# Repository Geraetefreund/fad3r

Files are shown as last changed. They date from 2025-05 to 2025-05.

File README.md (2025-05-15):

# fad3r

v0.2 / 2025-05-14

Improved preset storage in EEPROM. Faders can now have indiviual MIDI channels.  

Load preset:  
``` F0 7D 40 <preset> F7```

Store current CC/Channel values to preset:  
```F0 7D 41 <preset> F7```

Set CCs and Channels for preset (remember dec to hex!):  
```F0 7D 42 <preset> <cc1> <cc2> <cc3> <ch1> <ch2> <ch3> F7```  

Dump preset: ``` F0 7D 43 <preset> F7```  

Returns: ```F0 7D 43 <preset> <cc1> <cc2> <cc3> <ch1> <ch2> <ch3> F7```

Get current preset: 
``` F0 7D 44 00 F7``` returns ```F0 7D 44 <current preset> F7```

=================
v0.1 / 2020-02-12

Firmware for Teensy LC (legacy) controlling three faders via USB Midi  

https://www.pjrc.com/store/teensylc.html  
https://www.pjrc.com/teensy/td_midi.html  

``` F0 7D <cc1> <cc2> <cc3> F7```
remember to convert from dec to hex!

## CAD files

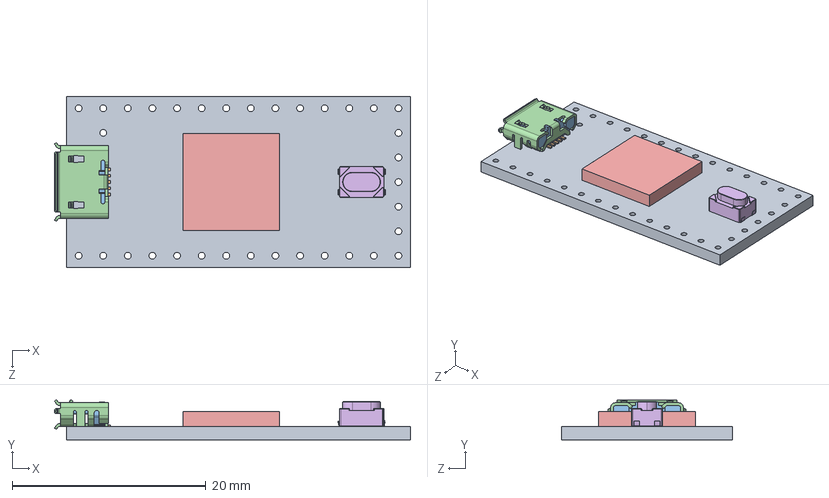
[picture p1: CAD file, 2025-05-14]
hardware/teensy.pretty-master/Teensy_4.0_Assembly.STEP
36.8 x 4.12 x 17.7 mm
Teensy_4.0_PCB
Micro USB-B Female 5Pin SMD
NXP iMXRT1062
SKRPACE010 v4

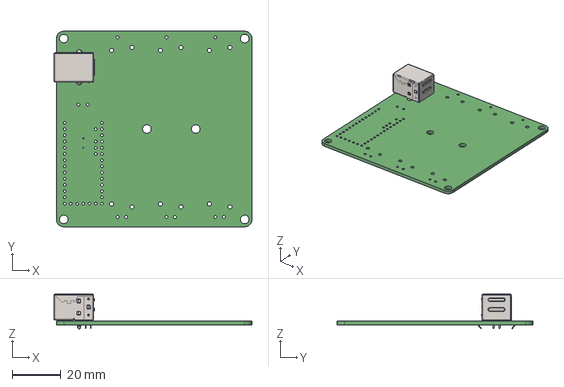
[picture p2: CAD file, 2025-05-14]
hardware/midi fader.step
81.0 x 80.0 x 14.2 mm

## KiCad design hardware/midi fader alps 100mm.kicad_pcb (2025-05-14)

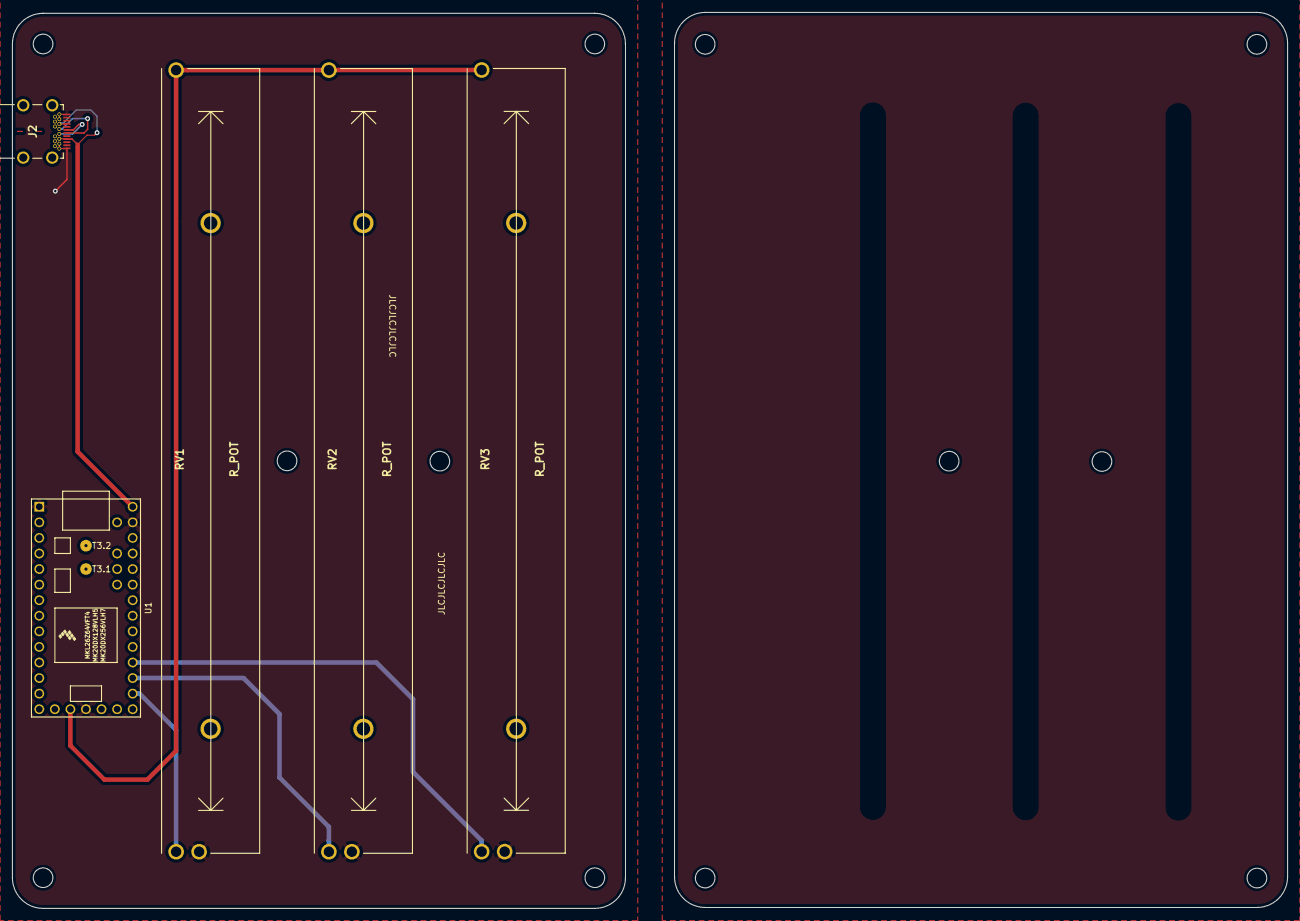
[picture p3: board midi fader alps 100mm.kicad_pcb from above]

Board: 2 copper layers, 100.0 x 146.0 mm, 5 parts (0 on the bottom side), 8 nets.

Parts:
J2: 632723300011
RV1, RV2, RV3: R_POT; Alps_RSA0N111900Q
U1: Teensy-LC; Teensy30_31_32_LC

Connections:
+3V3: RV1.3, RV2.3, RV3.3, U1.16
+5V: J2.A4, J2.A9, J2.B4, J2.B9, U1.33
/ADC_1: RV1.2, U1.21
/ADC_2: RV2.2, U1.22
/ADC_3: RV3.2, U1.23
/D+: J2.A6, J2.B6
/D-: J2.A7, J2.B7
GND: J2.1, J2.2, J2.A1, J2.A12, J2.B1, J2.B12, RV1.1, RV2.1, RV3.1, U1.1, U1.17, U1.32

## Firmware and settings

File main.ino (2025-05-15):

//Fad3r
//v0.2 / 2025-05-14

#include <EEPROM.h>

/* EEPROM layout - Teensy LC has 128 avaialble
Preset      Addr      Contents
0           0         CC1 CC2 CC3
            3         CH1 CH2 CH3
1           6         ...
...         ...       ...
Active      24        Current preset
*/
const int NUM_FADERS = 3;
const int NUM_PRESETS = 4;
const int BYTES_PER_PRESET = 6; // 3 CC + 3 CH
const int ACTIVE_PRESET_ADDR = NUM_PRESETS * BYTES_PER_PRESET; // stores location pointing to current preset

const int EEPROM_address[3] = {0, 1, 2};

// Fader analog input pins
const int pins[NUM_FADERS] = {A0, A1, A2}; // A0 = Fader 1, A1 = Fader 2, A2 = Fader 3

// MIDI CC and MIDI channel mappings
uint8_t cc[NUM_FADERS];
uint8_t channel[NUM_FADERS];

uint8_t currentPreset = 0;
bool sysexHandled = false;

// Previous analog values for change detection and smoothing
int oldValue[NUM_FADERS] = {0, 0, 0};

// Calling usbMIDI.getType() in every loop iteration is too laggy
// simple millis timer to the rescue.
unsigned long lastSysExCheck = 0;
const unsigned long sysexInterval = 20; // ms

void setup() {
  for (int i = 0; i < NUM_FADERS; i++) {
    pinMode(pins[i], INPUT);
  }

  currentPreset = EEPROM.read(ACTIVE_PRESET_ADDR);
  if (currentPreset >= NUM_PRESETS) currentPreset = 0;

  loadPreset(currentPreset);
}

void loop() {
  usbMIDI.read(); // Keep MIDI input buffer active

  // check for SysEx only every 20ms. Poor MIDI buffer gets too excited otherwise...
  if (millis() - lastSysExCheck >= sysexInterval) {
    handleSysEx();
  }

  // Fader reading and sending
  for (int i = 0; i < NUM_FADERS; i++) {
    int val = getFaderValue(i);
    if (val < 255) { // 255 means no significant change
      usbMIDI.sendControlChange(cc[i], val, channel[i]);
    }
  }
}

// Reads fader value and checks for significant change
int getFaderValue(int index) {
  int value = analogRead(pins[index]); // 0–1023
  if (abs(value - oldValue[index]) >= 8) { // Change threshold
    oldValue[index] = value;
    return (value < 8) ? 0 : (value >> 3); // Scale to 0–127
  }
  return 255; // No change
}

void loadPreset(uint8_t preset) {
  if (preset >= NUM_PRESETS) return;
  int base = preset * BYTES_PER_PRESET;
  for (int i = 0; i < NUM_FADERS; i++) {
    cc[i] = EEPROM.read(base + i);
    channel[i] = EEPROM.read(base + NUM_FADERS + i);
  }
}


void applyPreset(uint8_t preset) {
  loadPreset(preset);
  currentPreset = preset;
  EEPROM.update(ACTIVE_PRESET_ADDR, preset);
}

void savePreset(uint8_t preset) {
  if (preset >= NUM_PRESETS) return;
  int base = preset * BYTES_PER_PRESET;
  for (int i = 0; i < NUM_FADERS; i++) {
    EEPROM.update(base + i, cc[i]);
    EEPROM.update(base + NUM_FADERS + i, channel[i]);
  }
}

void dumpPreset(uint8_t preset) {
  if (preset >= NUM_PRESETS) return;
  uint8_t data[11]; // oops was 10 before.
  data[0] = 0xF0;
  data[1] = 0x7D;
  data[2] = 0x43; // Dump command
  data[3] = preset;
  int base = preset * BYTES_PER_PRESET;
  for (int i = 0; i < NUM_FADERS; i++) {
    data[4 + i] = EEPROM.read(base + i);  // CC
    data[4 + NUM_FADERS + i] = EEPROM.read(base + NUM_FADERS + i); // CH
  }
  data[10] = 0xF7;
  usbMIDI.sendSysEx(11, data, true);
}

void handleSysEx() {
  static uint8_t lastCommand = 0x00;
  static uint8_t lastPreset = 0xFF;

  if (usbMIDI.getType() == usbMIDI.SystemExclusive) {
    const uint8_t* data = usbMIDI.getSysExArray();
    unsigned int len = usbMIDI.getSysExArrayLength();

    if (len >= 5 && data[0] == 0xF0 && data[1] == 0x7D && data[len - 1] == 0xF7) {
      uint8_t command = data[2];
      uint8_t preset = data[3];

      // Avoid re-processing the same message repeatedly
      if (command == lastCommand && preset == lastPreset) return;

      lastCommand = command;
      lastPreset = preset;

      switch (command) {
        case 0x40: applyPreset(preset); break;
        case 0x41: savePreset(preset); break;
        case 0x42:
          if (len == 11 && preset < NUM_PRESETS) {
            int base = preset * BYTES_PER_PRESET;
            for (int i = 0; i < NUM_FADERS; i++) {
              EEPROM.update(base + i, data[4 + i]);
              EEPROM.update(base + NUM_FADERS + i, data[4 + NUM_FADERS + i]);
            }
            applyPreset(preset);
          }
          break;
        case 0x43: dumpPreset(preset); break;
        case 0x44: {
          uint8_t reply[5] = {0xF0, 0x7D, 0x44, currentPreset, 0xF7};
          usbMIDI.sendSysEx(5, reply, true);
        } break;
      }
    }
  } else {
    // Reset detection when SysEx is no longer active
    sysexHandled = false;
    // Reset last command to allow next SysEx message to be processed
    lastCommand = 0x00;
    lastPreset = 0xFF;
  }
}

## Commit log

2025-05-14 version 0.1 working with eeprom and sysex
    [Teensy_4.0_Assembly.STEP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]
2025-05-15 add sysex for get current preset
2025-05-15 fix: after sysex call, no need to wiggle a fader
    [main.ino]
